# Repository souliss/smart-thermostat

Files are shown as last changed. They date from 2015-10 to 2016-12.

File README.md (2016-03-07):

# souliss-smart-thermostat-WiFi


Wi-Fi Smart Thermostat based on Souliss IoT Framework

Here you have the development version of SST:
https://github.com/mcbittech/souliss-smart-thermostat-WiFi

Youtube link:
https://youtu.be/aof8ILJSSf4

# Example of layout 2:
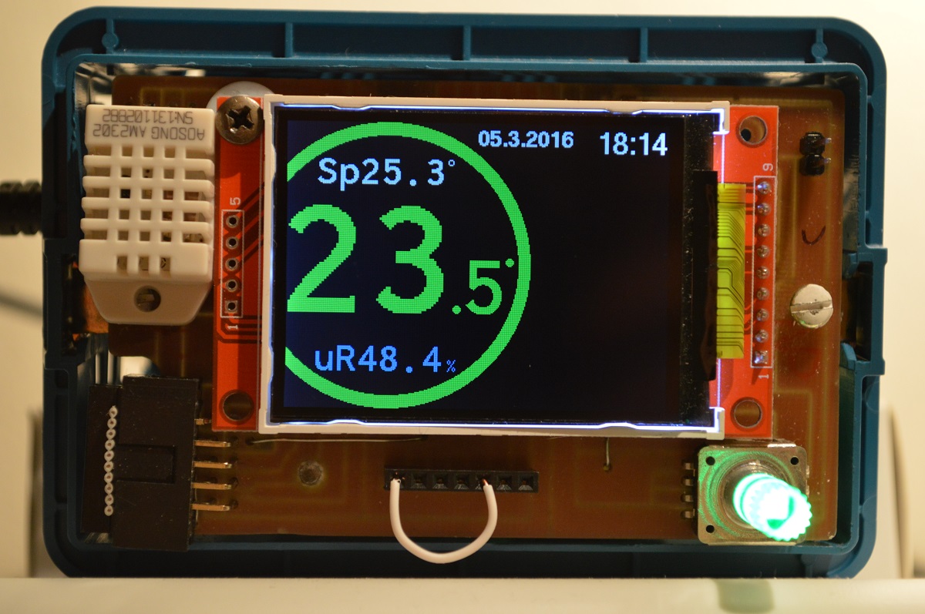
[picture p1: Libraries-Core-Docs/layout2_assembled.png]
layout2


# Example of layout 1:
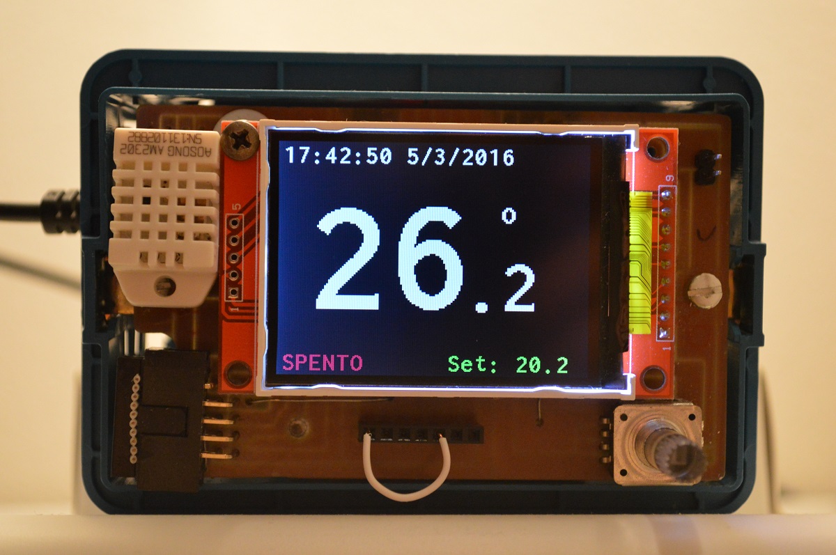
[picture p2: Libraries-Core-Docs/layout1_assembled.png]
layout2 layout1


# Example of chrono:
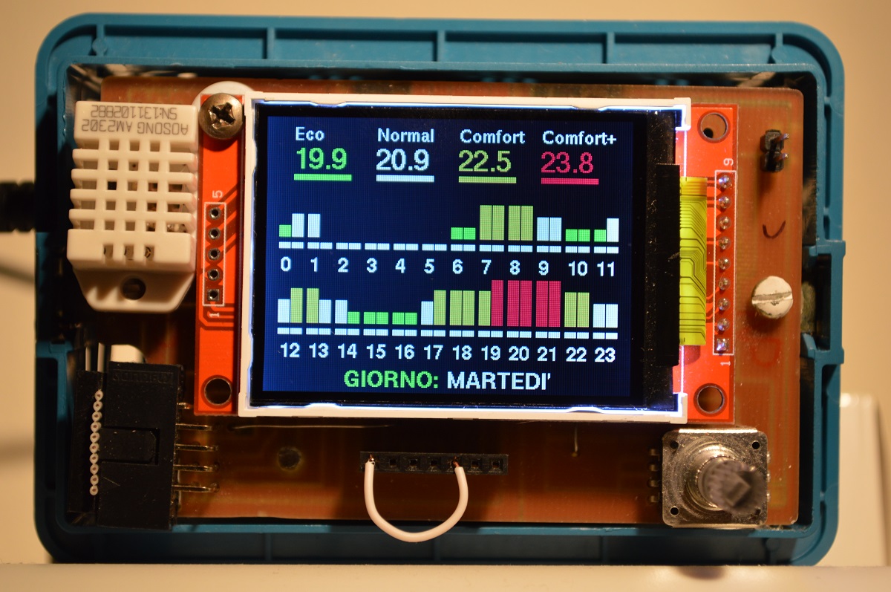
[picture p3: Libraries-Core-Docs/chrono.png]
chrono


# Bill of Material:
-Olimex ESP8266-EVB  
-ILI9341 with SPI connection, via UEXT connector  
-Rotary Encoder with pushbutton & status LED  
-DHT22 Temperature & Humidity Sensor  

# How to connect your system:
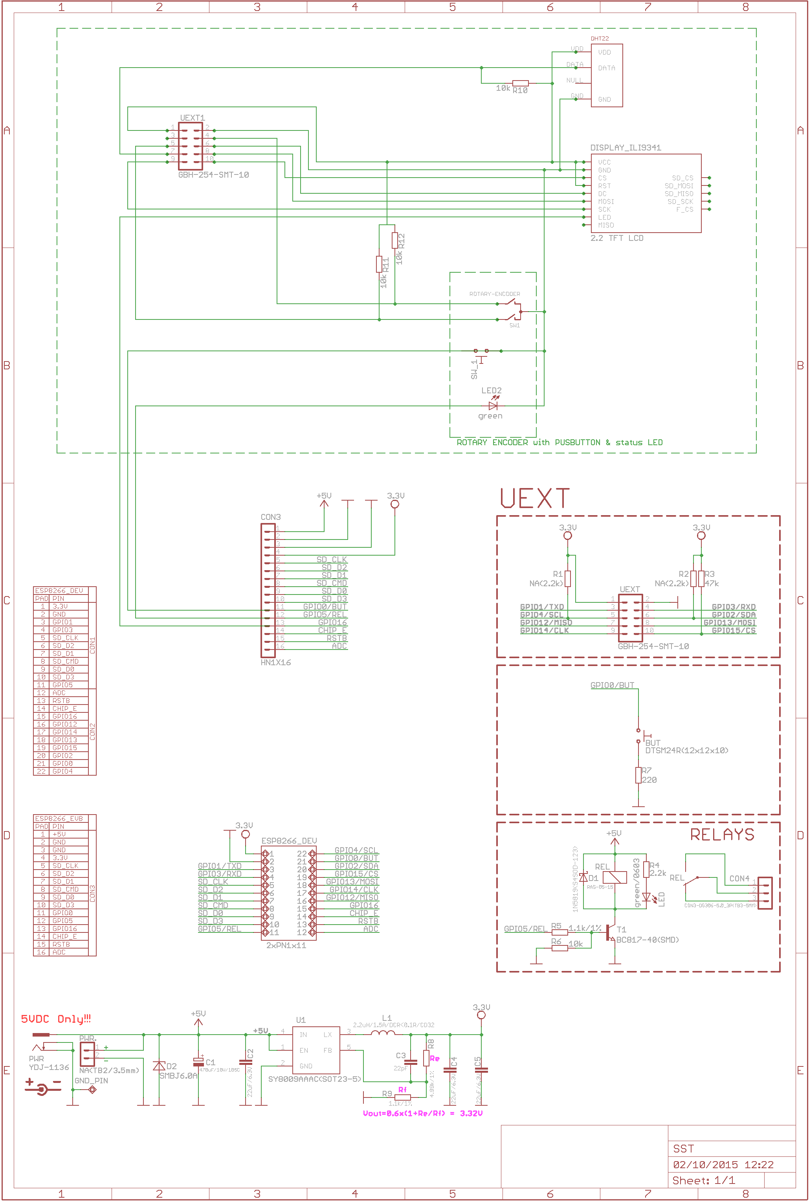
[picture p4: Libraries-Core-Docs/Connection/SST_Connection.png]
scheme


# Power up your system:
All the system require maximum about 200mA @5vdc, with relay ON and maximum brightness of the screen. 
Minimum power required about 65mA, with relay OFF and minimum brightness.

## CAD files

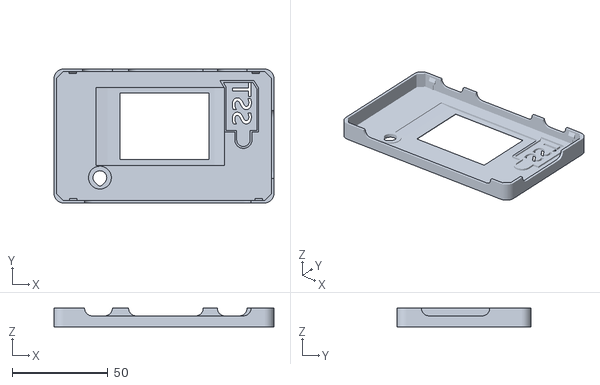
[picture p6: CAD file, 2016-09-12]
Libraries-Core-Docs/MOSTRINA_3D/COPERTURA (repaired).stl
115.0 x 70.0 x 9.70

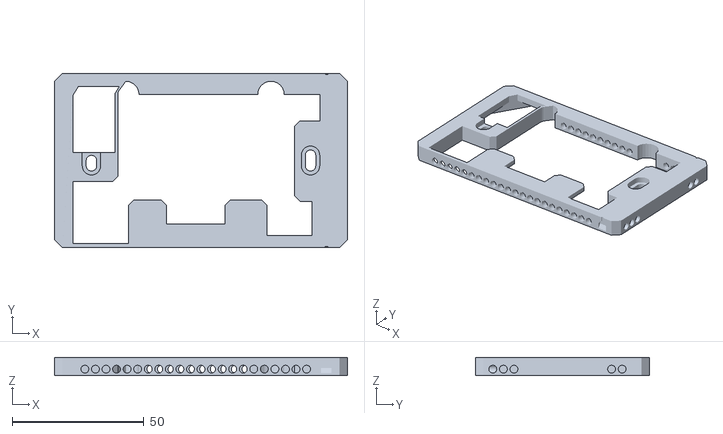
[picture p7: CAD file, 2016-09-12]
Libraries-Core-Docs/MOSTRINA_3D/SUPPORTO (repaired).stl
111.0 x 66.0 x 7.00

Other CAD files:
Libraries-Core-Docs/MOSTRINA_3D/Taglio.dwg
Libraries-Core-Docs/MOSTRINA_3D/Studio.skp

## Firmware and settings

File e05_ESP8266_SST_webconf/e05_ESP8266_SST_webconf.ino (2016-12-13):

/**************************************************************************
  Wi-Fi Smart Thermostat based on Souliss IoT Framework
    -Olimex ESP8266-EVB
    -ILI9341 with SPI connection, via UEXT connector
    -Rotary Encoder with pushbutton & status LED
    -DHT22 Temperature & Humidity Sensor

  This example is only supported on ESP8266.
  Developed by mcbittech & fazioa
***************************************************************************/
// Let the IDE point to the Souliss framework
#include "SoulissFramework.h"

//new customs Souliss_T3n_DeadBand and Souliss_T3n_Hysteresis
#define T3N_DEADBAND_INSKETCH
	#define Souliss_T3n_DeadBand      0.1     // Degrees Deadband
#define T3N_HYSTERESIS_INSKETCH
	#define Souliss_T3n_Hysteresis      0.1     // Degrees Hysteresis

#include <ESP8266WiFi.h>
#include <ESP8266WebServer.h>
#include <ESP8266mDNS.h>
#include <EEPROM.h>
#include "FS.h" //SPIFFS
#include <WiFiUdp.h>
#include <ArduinoOTA.h>
#include <MenuSystem.h>
#include <DHT.h>

// Configure the Souliss framework
#include "bconf/MCU_ESP8266.h"              /** Load the code directly on the ESP8266 */
#include "preferences.h"
#include "multiClick.h"

#if(DYNAMIC_CONNECTION)
#include "conf/RuntimeGateway.h"            // This node is a Peer and can became a Gateway at runtime
#include "conf/DynamicAddressing.h"         // Use dynamically assigned addresses
#include "conf/WEBCONFinterface.h"          // Enable the WebConfig interface
#include "connection_dynamic.h"
#else
#include "conf/IPBroadcast.h"
#include "connection_static.h"
#endif

#define USEEEPROM_INSKETCH
#define USEEEPROM             1


#include "Souliss.h"
#include "encoder.h"
#include "constants.h"
#include "display.h"
#include "display2.h"
#include "displayTopics.h"
#include "language.h"
#include "ntp.h"
#include <TimeLib.h>
#include "menu.h"
#include "crono.h"
#include "read_save.h"
#include "topics.h"
#include "pagesStruct.h"
//*************************************************************************
//*************************************************************************
Page SSTPage;

DHT dht(DHTPIN, DHTTYPE);
float temperature = 0;
float humidity = 0;
float fVal = 0;
float setpoint = 0;
float encoderValue_prec = 0;

//DISPLAY
////////////////////////////////////////////////////////////////////////////////////////////////////////////////
#include <SPI.h>
#include <Arduino.h>
#include "Ucglib.h"

int backLEDvalue = 0;
int backLEDvalueHIGH = BRIGHT_MAX;
int backLEDvalueLOW = BRIGHT_MIN_DEFAULT;
bool FADE = 1;
uint8_t mypayload_len = 0;
uint8_t mypayload[2];
float fTopic_C1_Output;
float fTopic_C2_Output;
float fTopic_C3_Output;
float fTopic_C4_Output;
float fTopic_C5_Output;
float fTopic_C6_Output;

boolean bChildLock = false;

// Menu
MenuSystem* myMenu;

// Use hardware SPI
Ucglib_ILI9341_18x240x320_HWSPI ucg(/*cd=*/ 2 , /*cs=*/ 15);

void EEPROM_Reset() {
  // Erase network configuration parameters from previous use of ZeroConf
  SERIAL_OUT.println("Store_Init");
  Store_Init();
  SERIAL_OUT.println("Store_Clear");
  Store_Clear();
  SERIAL_OUT.println("Store_Commit");
  Store_Commit();
  SERIAL_OUT.println("OK");

  // Print the EEPROM contents, if erase has been succesfull you should see only zeros.
  for (uint16_t i = 0; i < STORE__USABLESIZE; i++)
    SERIAL_OUT.println(Return_8bit(i));

  spiffs_Reset();
  ESP.reset();
}

void subscribeTopics() {
  if (sbscrbdata(TOPIC1, mypayload, &mypayload_len)) {
    float32((uint16_t*) mypayload,  &fTopic_C1_Output);
    SERIAL_OUT.print("TOPIC1: "); SERIAL_OUT.println(fTopic_C1_Output);
  } else if (sbscrbdata(TOPIC2, mypayload, &mypayload_len)) {
    float32((uint16_t*) mypayload,  &fTopic_C2_Output);
    SERIAL_OUT.print("TOPIC2: "); SERIAL_OUT.println(fTopic_C2_Output);
  } else if (sbscrbdata(TOPIC3, mypayload, &mypayload_len)) {
    float32((uint16_t*) mypayload,  &fTopic_C3_Output);
    SERIAL_OUT.print("TOPIC3: "); SERIAL_OUT.println(fTopic_C3_Output);
  } else if (sbscrbdata(TOPIC4, mypayload, &mypayload_len)) {
    float32((uint16_t*) mypayload,  &fTopic_C4_Output);
    SERIAL_OUT.print("TOPIC4: "); SERIAL_OUT.println(fTopic_C4_Output);
  } else if (sbscrbdata(TOPIC5, mypayload, &mypayload_len)) {
    float32((uint16_t*) mypayload,  &fTopic_C5_Output);
    SERIAL_OUT.print("TOPIC5: "); SERIAL_OUT.println(fTopic_C5_Output);
  } else if (sbscrbdata(TOPIC6, mypayload, &mypayload_len)) {
    float32((uint16_t*) mypayload,  &fTopic_C6_Output);
    SERIAL_OUT.print("TOPIC6: "); SERIAL_OUT.println(fTopic_C6_Output);
  }
}


void setSoulissDataChanged() {
  if (data_changed != Souliss_TRIGGED) {

    data_changed = Souliss_TRIGGED;
  }
}

void set_ThermostatModeOn(U8 slot) {
  SERIAL_OUT.println("set_ThermostatModeOn");
  memory_map[MaCaco_OUT_s + slot] |= Souliss_T3n_SystemOn;
  memory_map[MaCaco_OUT_s + slot] &= ~Souliss_T3n_HeatingMode;

  // Trig the next change of the state
  setSoulissDataChanged();
}
void set_ThermostatOff(U8 slot) {
  //memory_map[MaCaco_IN_s + slot] = Souliss_T3n_ShutDown;
  memory_map[MaCaco_OUT_s + SLOT_THERMOSTAT] &= ~ (Souliss_T3n_SystemOn | Souliss_T3n_FanOn1 | Souliss_T3n_FanOn2 | Souliss_T3n_FanOn3 | Souliss_T3n_CoolingOn | Souliss_T3n_HeatingOn);
  setSoulissDataChanged();
}
void set_DisplayMinBright(U8 slot, U8 val) {
  memory_map[MaCaco_OUT_s + slot + 1] = val;
  // Trig the next change of the state

  setSoulissDataChanged();
}

void encoderFunction() {
  encoder();
}

boolean getSoulissSystemState() {
  return memory_map[MaCaco_OUT_s + SLOT_THERMOSTAT] & Souliss_T3n_SystemOn;
}

boolean T_or_H_isNan = false;
boolean bFlagBegin = false;
void getTemp() {
  // Read temperature value from DHT sensor and convert from single-precision to half-precision
  fVal = dht.readTemperature();
  SERIAL_OUT.print("acquisizione Temperature: "); SERIAL_OUT.println(fVal);
  if (!isnan(fVal)) {
    temperature = fVal; //memorizza temperatura se non è Not A Number
    //Import temperature into T31 Thermostat
    ImportAnalog(SLOT_THERMOSTAT + 1, &temperature);
    ImportAnalog(SLOT_TEMPERATURE, &temperature);
  } else {
    bFlagBegin = true;
  }

  // Read humidity value from DHT sensor and convert from single-precision to half-precision
  fVal = dht.readHumidity();
  SERIAL_OUT.print("acquisizione Humidity: "); SERIAL_OUT.println(fVal);
  if (!isnan(fVal)) {
    humidity = fVal;
    ImportAnalog(SLOT_HUMIDITY, &humidity);
  } else {
    bFlagBegin = true;
  }

  if ( bFlagBegin) {
    //if DHT fail then try to reinit
    dht.begin();
    SERIAL_OUT.println(" dht.begin();");
  }
}

void initScreen() {
  ucg.clearScreen();
  SERIAL_OUT.println("clearScreen ok");
  if (getLayout1()) {
    SERIAL_OUT.println("HomeScreen Layout 1");

    display_layout1_HomeScreen(ucg, temperature, humidity, setpoint, getSoulissSystemState(), bChildLock);
    getTemp();
  }
  else if (getLayout2()) {
    SERIAL_OUT.println("HomeScreen Layout 2");
    getTemp();
    display_layout2_HomeScreen(ucg, temperature, humidity, setpoint);
    display_layout2_print_circle_white(ucg);
    display_layout2_print_datetime(ucg);
    if (ACTIVATETOPICSPAGE == 1) {
      alwaysdisplayTopicsHomePageLayout2(ucg, fTopic_C1_Output, fTopic_C2_Output, fTopic_C3_Output, fTopic_C4_Output, fTopic_C5_Output, fTopic_C6_Output);
    }
    display_layout2_print_circle_black(ucg);
    yield();
    display_layout2_print_circle_green(ucg);
  }
}
void setSetpoint(float setpoint) {
  //SERIAL_OUT.print("Away: ");SERIAL_OUT.println(memory_map[MaCaco_OUT_s + SLOT_AWAY]);
  if (memory_map[MaCaco_OUT_s + SLOT_AWAY]) {
    //is Away

  } else {
    //is not Away
  }
  Souliss_HalfPrecisionFloating((memory_map + MaCaco_OUT_s + SLOT_THERMOSTAT + 3), &setpoint);
}
void bright(int lum) {
  int val = ((float)lum / 100) * 1023;
  if (val > 1023) val = 1023;
  if (val < 0) val = 0;
  analogWrite(BACKLED, val);
}

void publishHeating_ON_OFF() {
  //code from Souliss_nDigOut(...
  //nDigOut(RELE, Souliss_T3n_HeatingOn, SLOT_THERMOSTAT);    // Heater

  if (memory_map[MaCaco_OUT_s + SLOT_THERMOSTAT] & Souliss_T3n_HeatingOn)
    pblshdata(SST_HEAT_ONOFF, &HEAT_ON, 1);
  else
    pblshdata(SST_HEAT_ONOFF, &HEAT_OFF, 1);
}



void setup()
{

  SERIAL_OUT.begin(115200);

  //SPIFFS
  /////////////////////////////////////////////////////////////////////////////////////////////////////////
  SPIFFS.begin();
  File  sst_spiffs_verifica = SPIFFS.open("/sst_settings.json", "r");
  if (!sst_spiffs_verifica) {
    Serial.println(" ");
    Serial.println("Non riesco a leggere sst_settings.json! formatto la SPIFFS...");
    SPIFFS.format();
    Serial.println("Spiffs formatted");
    ReadAllSettingsFromPreferences();
    ReadCronoMatrixSPIFFS();
  }
  else
  {
    ReadAllSettingsFromSPIFFS();
    ReadCronoMatrixSPIFFS();
    backLEDvalueLOW = getDisplayBright();
  }

  //DISPLAY INIT
  /////////////////////////////////////////////////////////////////////////////////////////////////////////
  ucg.begin(UCG_FONT_MODE_SOLID);

  //SPI Frequency
  SPI.setFrequency(80000000);

  ucg.setColor(0, 0, 0);
  ucg.setRotate90();
  //BACK LED
  /////////////////////////////////////////////////////////////////////////////////////////////////////////
  digitalWrite(BACKLED, HIGH);
  pinMode(BACKLED, OUTPUT);                     // Background Display LED

  display_print_splash_screen(ucg);
  Initialize();

#if(DYNAMIC_CONNECTION)
  DYNAMIC_CONNECTION_Init();
#else
#if(DHCP_OPTION)
  STATIC_CONNECTION_Init_DHCP();
#else
  STATIC_CONNECTION_Init_STATICIP();
#endif
#endif


  //*************************************************************************
  //*************************************************************************
  Set_T52(SLOT_TEMPERATURE);
  Set_T53(SLOT_HUMIDITY);
  Set_T19(SLOT_BRIGHT_DISPLAY);
  Set_T11(SLOT_AWAY);

  //set default mode
  Set_Thermostat(SLOT_THERMOSTAT);
  set_ThermostatModeOn(SLOT_THERMOSTAT);
  set_DisplayMinBright(SLOT_BRIGHT_DISPLAY, backLEDvalueLOW);

  // Define output pins
  pinMode(RELE, OUTPUT);    // Heater
  dht.begin();

  //ENCODER
  /////////////////////////////////////////////////////////////////////////////////////////////////////////
  pinMode (ENCODER_PIN_A, INPUT_PULLUP);
  pinMode (ENCODER_PIN_B, INPUT_PULLUP);
  attachInterrupt(digitalPinToInterrupt(ENCODER_PIN_A), encoderFunction, CHANGE);
  attachInterrupt(digitalPinToInterrupt(ENCODER_PIN_B), encoderFunction, CHANGE);
  // SWITCH ENCODER
  digitalWrite(BACKLED, HIGH);
  pinMode(ENCODER_SWITCH, INPUT);

  //NTP
  /////////////////////////////////////////////////////////////////////////////////////////////////////////
  initNTP();
  delay(1000);
  //*************************************************************************
  //*************************************************************************

  //MENU
  /////////////////////////////////////////////////////////////////////////////////////////////////////////
  initMenu();
  myMenu = getMenu();


  // Init the OTA
  // Set Hostname.
  String hostname(HOSTNAME);
  hostname += String(ESP.getChipId(), HEX);
  SERIAL_OUT.print("set OTA hostname: "); SERIAL_OUT.println(hostname);
  ArduinoOTA.setHostname((const char *)hostname.c_str());
  ArduinoOTA.begin();

  // Init HomeScreen
  initScreen();
}

void loop()
{
  EXECUTEFAST() {
    UPDATEFAST();

    switch (SSTPage.actualPage) {
      case PAGE_MENU :
        if (getMenuEnabled() && !bChildLock) {
          //Bright high if menu enabled
          FADE = 1;
          //Menu Command Section
          if (getEncoderValue() != encoderValue_prec)
          {
            if (getEncoderValue() > encoderValue_prec) {
              //Menu DOWN
              myMenu->next();
            } else {
              //Menu UP
              myMenu->prev();
            }
            printMenuMove(ucg);
            encoderValue_prec = getEncoderValue();
          }
        }
        if (getMenuEnabled() && !digitalRead(ENCODER_SWITCH)) {
          //IF MENU ENABLED
          myMenu->select(true);
          ucg.clearScreen();
          printMenu(ucg);
        }

    }

    SHIFT_50ms(0) {
      //set point attuale
      setpoint = Souliss_SinglePrecisionFloating(memory_map + MaCaco_OUT_s + SLOT_THERMOSTAT + 3);
      //Stampa il setpoint solo se il valore dell'encoder è diverso da quello impostato nel T31
      switch (SSTPage.actualPage) {
        case PAGE_MENU :
          if (!getMenuEnabled()) {
            SSTPage.actualPage = PAGE_HOME;
            initScreen();
            setUIChanged();
          }
          break;
        case PAGE_CRONO :
          break;
        default:
          if (arrotonda(getEncoderValue()) != arrotonda(encoderValue_prec) && !bChildLock) {
            FADE = 1;
            //TICK TIMER
            timerDisplay_setpoint_Tick();
            //SETPOINT PAGE ////////////////////////////////////////////////////////////////

            if (getLayout1()) {
              SERIAL_OUT.println("display_setpointPage - layout 1");
              display_layout1_background(ucg, arrotonda(getEncoderValue()) - arrotonda(setpoint));
			  
              display_layout1_setpointPage(ucg, getEncoderValue(), temperature, humidity, getSoulissSystemState());
            }
            else if (getLayout2()) {
              SERIAL_OUT.println("display_setpointPage - layout 2");
              display_layout2_Setpoint(ucg, getEncoderValue(), getSoulissSystemState(), bChildLock);
            }
          }
          encoderValue_prec = getEncoderValue();
          break;
      }
    }
    SHIFT_50ms(3) {
      Logic_T19(SLOT_BRIGHT_DISPLAY);
      Logic_T11(SLOT_AWAY);
    }

    SHIFT_110ms(0) {
      if (!getMenuEnabled()) {
        if (timerDisplay_setpoint()) {
          //timeout scaduto
          display_layout1_background_black(ucg);
          setEncoderValue(setpoint);
        } else {
          //timer non scaduto. Memorizzo
          setpoint = getEncoderValue();
          //memorizza il setpoint nel T31
          setSetpoint(setpoint);

          // Trig the next change of the state
          setSoulissDataChanged();
        }
      }
    }


    SHIFT_110ms(4) {
      //SWITCH ENCODER
      //Al click in base al valore attuale di SSTPage, si imposta la pagina successiva

      int b = checkButton(ENCODER_SWITCH);
      if (b == 2) SERIAL_OUT.println("Double Click");
      if (b == 3) {
        SERIAL_OUT.println("Hold");
        bChildLock = !bChildLock;
        SERIAL_OUT.print("Child Lock: "); SERIAL_OUT.println(bChildLock);
        ucg.clearScreen();
        setUIChanged();
        if (getLayout2()) {
          //Reinizializzo la Home per mostrare subito il cambio stato locked/unlocked e non aspettare il refresh
          initScreen();
        }
      }
      if (b == 4) SERIAL_OUT.println("Long Hold");

      if (b == 1) {
        switch (SSTPage.actualPage) {
          case PAGE_HOME:
            if (ACTIVATETOPICSPAGE > 0) {
              SERIAL_OUT.println("from PAGE_HOME to PAGE_TOPICS1");
              SSTPage.actualPage = PAGE_TOPICS1;
              setUIChanged();
            } else {
              SERIAL_OUT.println("from PAGE_HOME to PAGE_MENU");
              SSTPage.actualPage = PAGE_MENU;
              setUIChanged();
              ucg.clearScreen();
              setMenuEnabled();
              //se system and UI changed
              setUIChanged();
              SERIAL_OUT.println("Print Menu");
              printMenu(ucg);
            }
            break;
          case PAGE_TOPICS1:
            if (TOPICSPAGESNUMBER == 1) {
              SERIAL_OUT.println("from PAGE_TOPICS1 to PAGE_MENU");
              SSTPage.actualPage = PAGE_MENU;

              setUIChanged();
              ucg.clearScreen();
              setMenuEnabled();

              SERIAL_OUT.println("Print Menu");
              printMenu(ucg);
            }
            else if (TOPICSPAGESNUMBER == 2) {
              SERIAL_OUT.println("from PAGE_TOPICS1 to PAGE_TOPICS2");
              SSTPage.actualPage = PAGE_TOPICS2;
              setUIChanged();
            }
            break;
          case PAGE_TOPICS2:
            SERIAL_OUT.println("from PAGE_TOPICS2 to PAGE_MENU");
            SSTPage.actualPage = PAGE_MENU;
            setUIChanged();
            ucg.clearScreen();
            setMenuEnabled();
            //se system and UI changed
            setUIChanged();
            SERIAL_OUT.println("Print Menu");
            printMenu(ucg);
            break;
          case PAGE_MENU:

            break;
          case PAGE_CRONO:

            break;
        }
      } else {
        //se progCrono è attivo allora passo alla pagina CRONO
        if (getProgCrono()) {
          SSTPage.actualPage = PAGE_CRONO;
          byte menu;
          SERIAL_OUT.println("Crono");
          ucg.clearScreen();
          drawCrono(ucg);
          SERIAL_OUT.println("drawCrono ok");
          menu = 1;
          //save encoder value before crono programmation
          setpoint = getEncoderValue();
          while (menu == 1 && exitmainmenu() == 0) {
            setDay(ucg);
            drawBoxes(ucg);
            setBoxes(ucg);
            if (exitmainmenu())
            {
              SERIAL_OUT.println("from PAGE_CRONO to PAGE_HOME");
              SSTPage.actualPage = PAGE_HOME;
              initScreen();
              setUIChanged();
              menu = 0;
            }
	  yield();	  
          }
          //restore encoder value
          setEncoderValue(setpoint);
        }
      }
    }

    SHIFT_210ms(0) {
      //FADE
      if (FADE == 0) {
        //Raggiunge il livello di luminosità minima, che può essere variata anche da SoulissApp
        if ( backLEDvalue != backLEDvalueLOW) {
          if ( backLEDvalue > backLEDvalueLOW) {
            backLEDvalue -= BRIGHT_STEP_FADE_OUT;
          } else {
            backLEDvalue += BRIGHT_STEP_FADE_OUT;
          }
          bright(backLEDvalue);
        }
      } else  if (FADE == 1 && backLEDvalue < backLEDvalueHIGH) {
        backLEDvalue +=  BRIGHT_STEP_FADE_IN;
        bright(backLEDvalue);
      }
    }

    SHIFT_210ms(2) {   // We process the logic and relevant input and output
      // Update topics in layout2 home page
      if (getLayout2()) {
        if (ACTIVATETOPICSPAGE == 1 && SSTPage.actualPage == PAGE_HOME) {
          displayTopicsHomePageLayout2(ucg, fTopic_C1_Output, fTopic_C2_Output, fTopic_C3_Output, fTopic_C4_Output, fTopic_C5_Output, fTopic_C6_Output);
        }
      }
    }

    FAST_510ms() {
      //*************************************************************************
      //*************************************************************************
      Logic_Thermostat(SLOT_THERMOSTAT);
            
      // Start the heater and the fans
      nDigOut(RELE, Souliss_T3n_HeatingOn, SLOT_THERMOSTAT);    // Heater


      // We are not handling the cooling mode, if enabled by the user, force it back
      // to disable
      if (mOutput(SLOT_THERMOSTAT) & Souliss_T3n_CoolingOn)
        mOutput(SLOT_THERMOSTAT) &= ~Souliss_T3n_CoolingOn;

      //if menu disabled and nothing changed
      if (SSTPage.actualPage != PAGE_MENU) {
        if (!getSystemChanged()) {
          if (getLocalSystem() != getSoulissSystemState())
            setSystem(getSoulissSystemState());
        }
      }

      //*************************************************************************
      //*************************************************************************

      Logic_T52(SLOT_TEMPERATURE);
      Logic_T53(SLOT_HUMIDITY);
    }

    FAST_710ms() {
      //HOMESCREEN ////////////////////////////////////////////////////////////////
      ///update homescreen only if menu exit
      if (getSystemChanged()) {
        //EXIT MENU - Actions
        //write min bright on T19
        memory_map[MaCaco_OUT_s + SLOT_BRIGHT_DISPLAY + 1] = getDisplayBright();
        SERIAL_OUT.print("Set Display Bright: "); SERIAL_OUT.println(memory_map[MaCaco_OUT_s + SLOT_BRIGHT_DISPLAY + 1]);

        //write system ON/OFF
        if (getLocalSystem()) {

          //ON
          SERIAL_OUT.println("Set system ON ");
          set_ThermostatModeOn(SLOT_THERMOSTAT);        // Set System On

        } else {

          //OFF
          SERIAL_OUT.println("Set system OFF ");
          set_ThermostatOff(SLOT_THERMOSTAT);
        }
        memory_map[MaCaco_IN_s + SLOT_THERMOSTAT] = Souliss_T3n_RstCmd;          // Reset
        // Trig the next change of the state
        setSoulissDataChanged();
        SERIAL_OUT.println("Init Screen");
        setUIChanged();
        initScreen();

        resetSystemChanged();
      }
    }

    FAST_2110ms() {

      //Crono Status in Layout 2
      if (getCrono() && getLayout2() && SSTPage.actualPage == PAGE_HOME ) {

        if (checkCronoStatus(ucg) == 0) //OFF
        {
          ucg.setColor(0, 0, 0);       // black
          ucg.drawDisc(156, 50, 5, UCG_DRAW_ALL);
          ucg.drawDisc(165, 62, 6, UCG_DRAW_ALL);
          ucg.drawDisc(173, 77, 7, UCG_DRAW_ALL);
          ucg.drawDisc(179, 95, 8, UCG_DRAW_ALL);
        }

        if (checkCronoStatus(ucg) == 1) //ECO
        {
          ucg.setColor( 102, 255, 0);       // Verde
          ucg.drawDisc(156, 50, 5, UCG_DRAW_ALL);
          ucg.setColor(0, 0, 0);       // black
          ucg.drawDisc(165, 62, 6, UCG_DRAW_ALL);
          ucg.drawDisc(173, 77, 7, UCG_DRAW_ALL);
          ucg.drawDisc(179, 95, 8, UCG_DRAW_ALL);
        }
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

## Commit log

2015-10-23 Added power info on README.md
2016-03-05 Libraries + new photos
    [SST.sch]
2016-06-12 Development stage at 12/06/2016 Code compile with IDE 1.6.8, ESP Core 2.2.0. OTA work good Some enhancement to do Some bugfix to do
2016-08-17 Ver 0.9
    IDE 1.6.10
    Core 2.3.0
    - Two Configurable Topic pages
    - Child Lock with long press
    - some enhancement done and bug fixed
    Know bugs:
    - some problems with LAYOUT_CIRCULAR
    - sometime SST reset in crono programming page
    [e05_ESP8266_SST_webconf.ino]
2016-08-17 Added used libraries and 3D printer files
    [Studio.skp, Taglio.dwg]
2016-08-21 topics alignment some partial bugfix to layout2
    [e05_ESP8266_SST_webconf.ino]
2016-09-12 For 3D Printer, STL files
    [COPERTURA (repaired).stl, SUPPORTO (repaired).stl]
2016-10-02 Publish message HEAT ON or OFF every 7 seconds
    #define SST_HEAT_ONOFF 0xF001,0x0B
    U8 HEAT_ON = 0X01;
    U8 HEAT_OFF = 0X00;
2016-12-03 - Constant TIMER_DISPLAY_SETPOINT to 4 seconds - some bugfix and display for layout2 - other minor bugfix - new customs Souliss_T3n_DeadBand and Souliss_T3n_Hysteresis (need to updade souliss framewo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
2016-12-11 cdj mod suggested by Flavio to eliminate reset during progcrono
    [e05_ESP8266_SST_webconf.ino]
